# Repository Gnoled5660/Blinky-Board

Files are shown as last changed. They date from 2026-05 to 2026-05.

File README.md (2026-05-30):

Bildschirmfoto 2026-05-30 um 00 24 46

# Blinky-Board

This is my first ever designed PCB! With no experience and knowledge, I decided to follow a guide that CAN and Tanishq made. Their guide is super well done and gave me everything I needed to understand what I was doing. This PCB is a Blinky Board with a timer, so that the LEDs keep blinking after another. I have never made a PCB before and I was always afraid to make my own, because it seemed so overwhelming. But now I have realised that it isn't that difficult after all. I got familiar with using KiCad and I look forward to design more custom PCBs of my own. 

The first step was to wire the logical symbols. The PCB is mainly split into two section. One section is the clock/timer that sends signals to the LED controller. The other section is the LED controller, that controls the LEDs directly. 

Bildschirmfoto 2026-05-30 um 00 23 44

The next step was to assign the footprints. After assigning them, I needed to actually wire them. Since this is a two layer PCB, it was either first layer or second layer. I tried to organize the wires but it felt impossible. In the end, I managed to wire everything. However, it looks super chaotic to me. I will try and do better next time! Some 3D models were not available in KiCad which is why, I had to download them from a website.

I added a bunch of memes on the board, so that it doesn't look empty. It looks really cool to me with all the prints on the board.

Bildschirmfoto 2026-05-29 um 20 34 48

Zine

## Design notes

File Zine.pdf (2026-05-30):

# My first Blinky Board

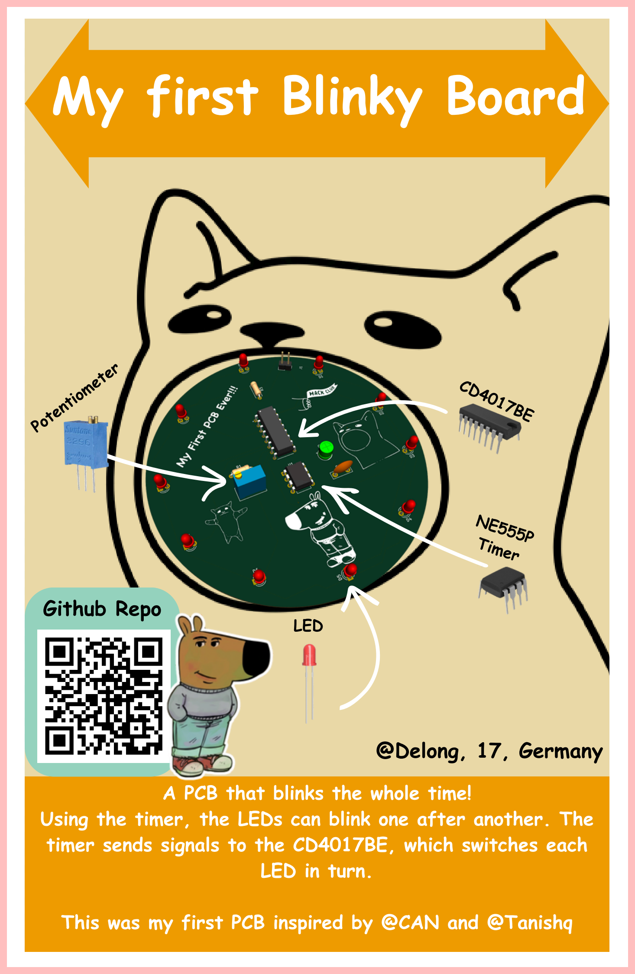
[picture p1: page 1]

Github Repo

@Delong, 17, Germany

CD4017BE

NE555P
Timer

LED

A PCB that blinks the whole time! Using the timer, the LEDs can blink one after another. The timer sends signals to the CD4017BE, which switches each LED in turn.

This was my first PCB inspired by @CAN and @Tanishq

Potentiometer

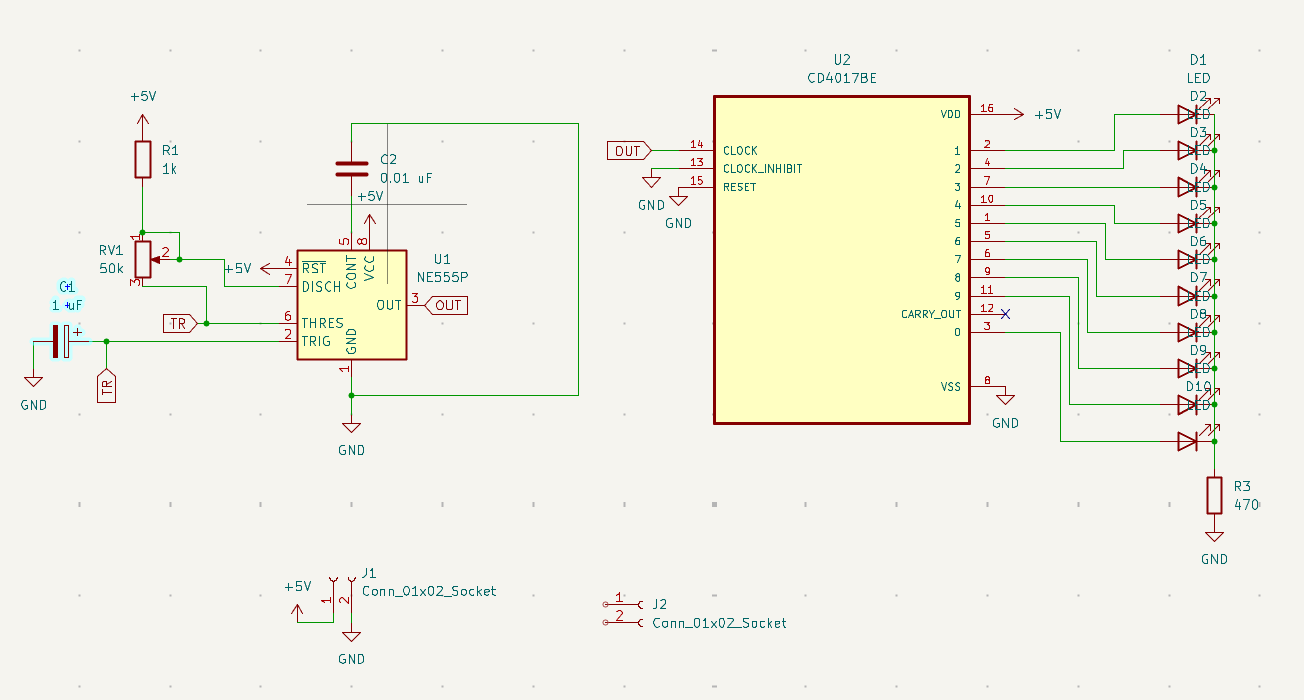
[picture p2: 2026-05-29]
Schematic/Schematic Symbol.png

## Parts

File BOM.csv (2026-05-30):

Name | Function | Links | Cost (USD) | Quantity
Capacitor | Polarized capacitor | https://funduinoshop.com/en/components/passive-components/capacitors/electrolytic-capacitor-1uf/10v-wired | 0.35 | 1
Capacitor | Unpolarized capacitor | https://www.ato.com/0-01μf-100v-ceramic-capacitor | 01.04 | 1
LED | LED Light | https://www.reichelt.de/de/de/shop/produkt/led_5_mm_bedrahtet_rot_125_mcd_50_-230920?PROVID=2788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 | 01.05 | 10
Resistor | Protect LED | https://www.reichelt.de/de/de/shop/produkt/widerstand_metalloxidschicht_470_ohm_0414_2_w_5_-2354 | 0.15 | 1
Resistor | Used as signal transmission | https://www.reichelt.de/de/de/shop/produkt/melf_widerstand_0204_1k_ohm_400_mw_1_-277763 | 0.08 | 1
Potentiometer | regulate LED speed | https://www.reichelt.de/de/de/shop/produkt/praezisionspotentiometer_25_gaenge_stehend_50_kohm-2710 | 2.10 | 1
NE555P | Timer LED light ticks | https://www.reichelt.de/de/de/shop/produkt/timer-ic_typ_555_dip-8-13397 | 0.3 | 1
CD4017BE | Control the LED | https://www.reichelt.de/de/de/shop/produkt/flip-flop_d-type_cmos_3_15_v_dip-16-12564 | 01.05 | 1
PCB | Main Circuit Board | https://jlcpcb.com | 9 | 1

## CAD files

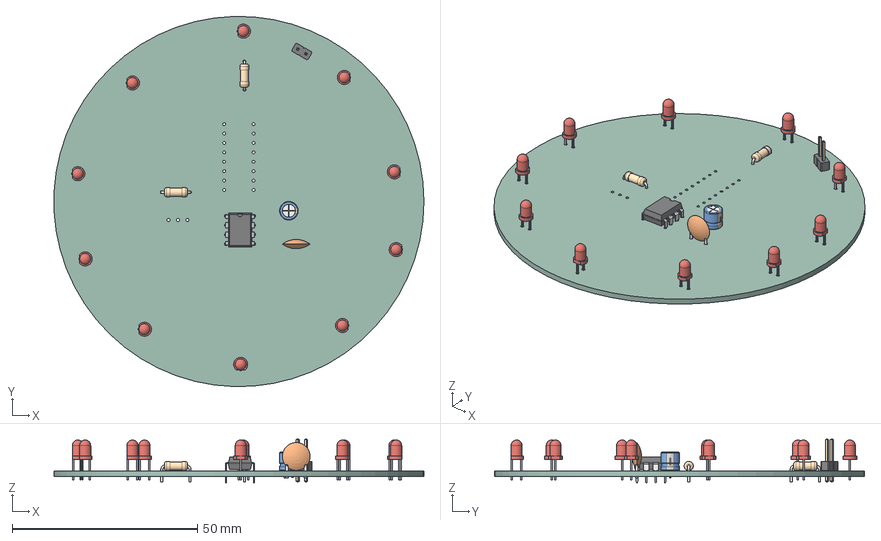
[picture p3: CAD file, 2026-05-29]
Schematic/3D Model.step
99.9 x 100.0 x 11.8 mm
LED_D3.0mm x 10
R_Axial_DIN0207_L63mm_D25mm_P762mm_Horizontal x 2
PinHeader_1x02_P254mm_Vertical
DIP-8_W7.62mm
CP_Radial_D50mm_P200mm
C_Disc_D75mm_W25mm_P500mm
Blinky Board_PCB

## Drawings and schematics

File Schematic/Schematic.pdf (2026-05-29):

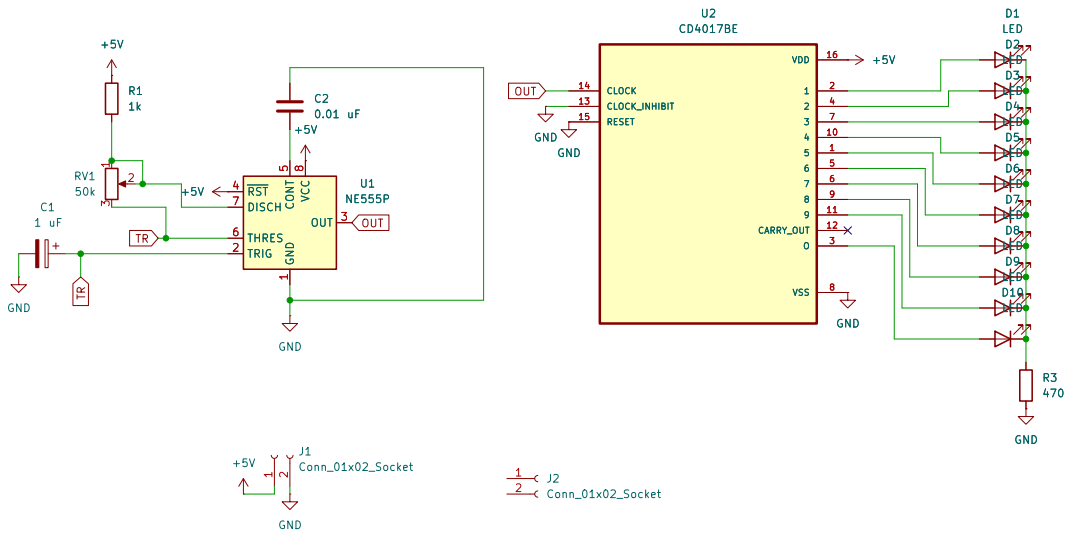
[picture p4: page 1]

Size: A4 | Rev:
KiCad E.D.A. 10.0.3 | Id: 1/1

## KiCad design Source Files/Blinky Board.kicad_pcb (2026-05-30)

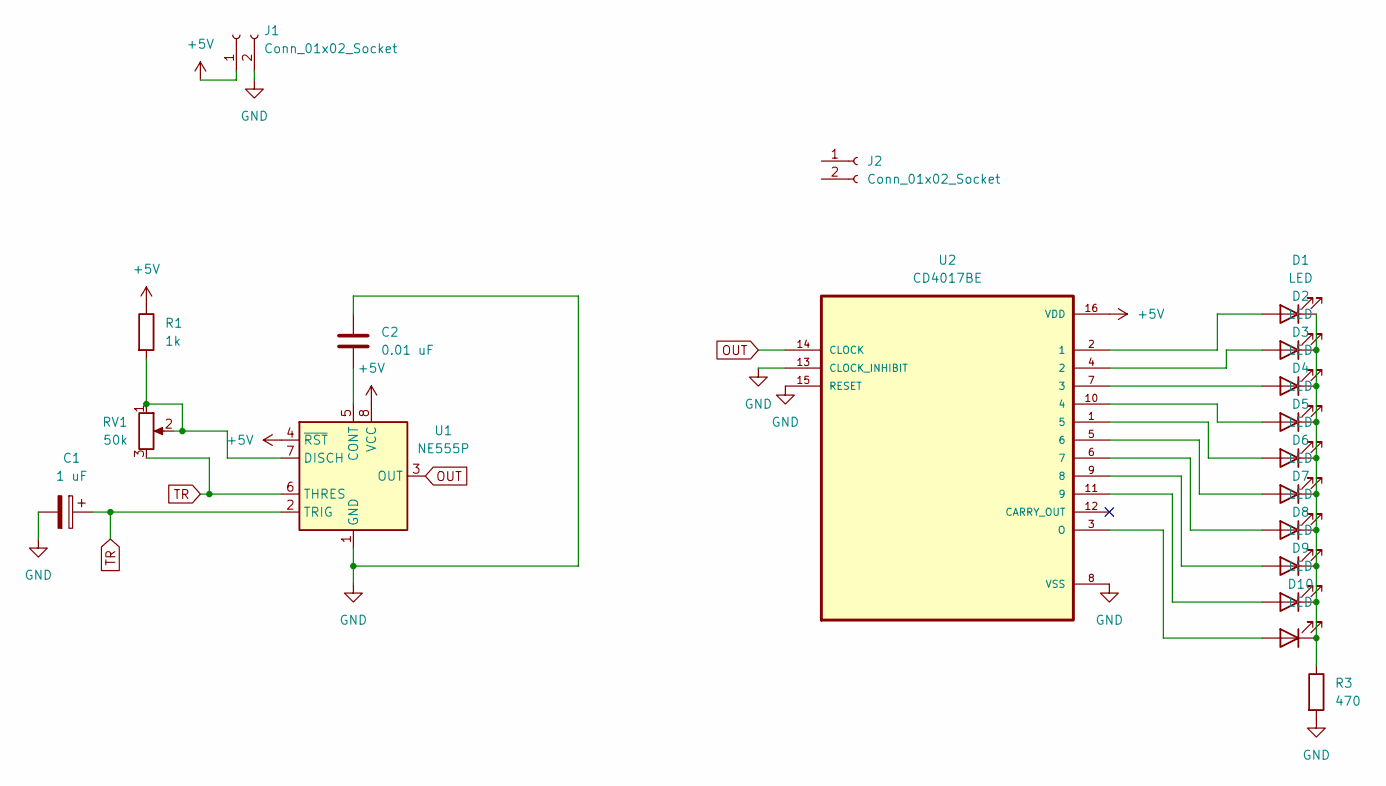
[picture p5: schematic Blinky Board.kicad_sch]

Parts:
C1: 1 uF; CP_Radial_D5.0mm_P2.00mm
C2: 0.01 uF; C_Disc_D7.5mm_W2.5mm_P5.00mm
D1, D2, D3, D4, D5, D6, D7, D8, D9, D10: LED; LED_D3.0mm
J1, J2: Conn_01x02_Socket; PinHeader_1x02_P2.54mm_Vertical
R1: 1k; R_Axial_DIN0207_L6.3mm_D2.5mm_P7.62mm_Horizontal
R3: 470; R_Axial_DIN0207_L6.3mm_D2.5mm_P7.62mm_Horizontal
RV1: 50k; Potentiometer_Vishay_T93YA_Vertical
U1: NE555P; DIP-8_W7.62mm
U2: CD4017BE; DIP794W45P254L1969H508Q16

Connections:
+5V: J1.1, R1.1, U1.4 (~RST), U1.8 (VCC), U2.16 (VDD)
GND: C1.2, C2.1, J1.2, R3.2, U1.1 (GND), U2.8 (VSS), U2.13 (CLOCK_INHIBIT), U2.15 (RESET)
unnamed: D1.2 (A), U2.2 (1)
unnamed: D1.1 (K), D2.1 (K), D3.1 (K), D4.1 (K), D5.1 (K), D6.1 (K), D7.1 (K), D8.1 (K), D9.1 (K), D10.1 (K), R3.1
unnamed: D2.2 (A), U2.4 (2)
unnamed: D3.2 (A), U2.7 (3)
unnamed: D4.2 (A), U2.10 (4)
unnamed: D5.2 (A), U2.1 (5)
unnamed: D6.2 (A), U2.5 (6)
unnamed: D7.2 (A), U2.6 (7)
unnamed: D8.2 (A), U2.9 (8)
unnamed: D9.2 (A), U2.11 (9)
unnamed: D10.2 (A), U2.3 (O)
unnamed: C2.2, U1.5 (CONT)
unnamed: R1.2, RV1.1, RV1.2, U1.7 (DISCH)
OUT: U1.3 (OUT), U2.14 (CLOCK)
TR: C1.1, RV1.3, U1.2 (TRIG), U1.6 (THRES)

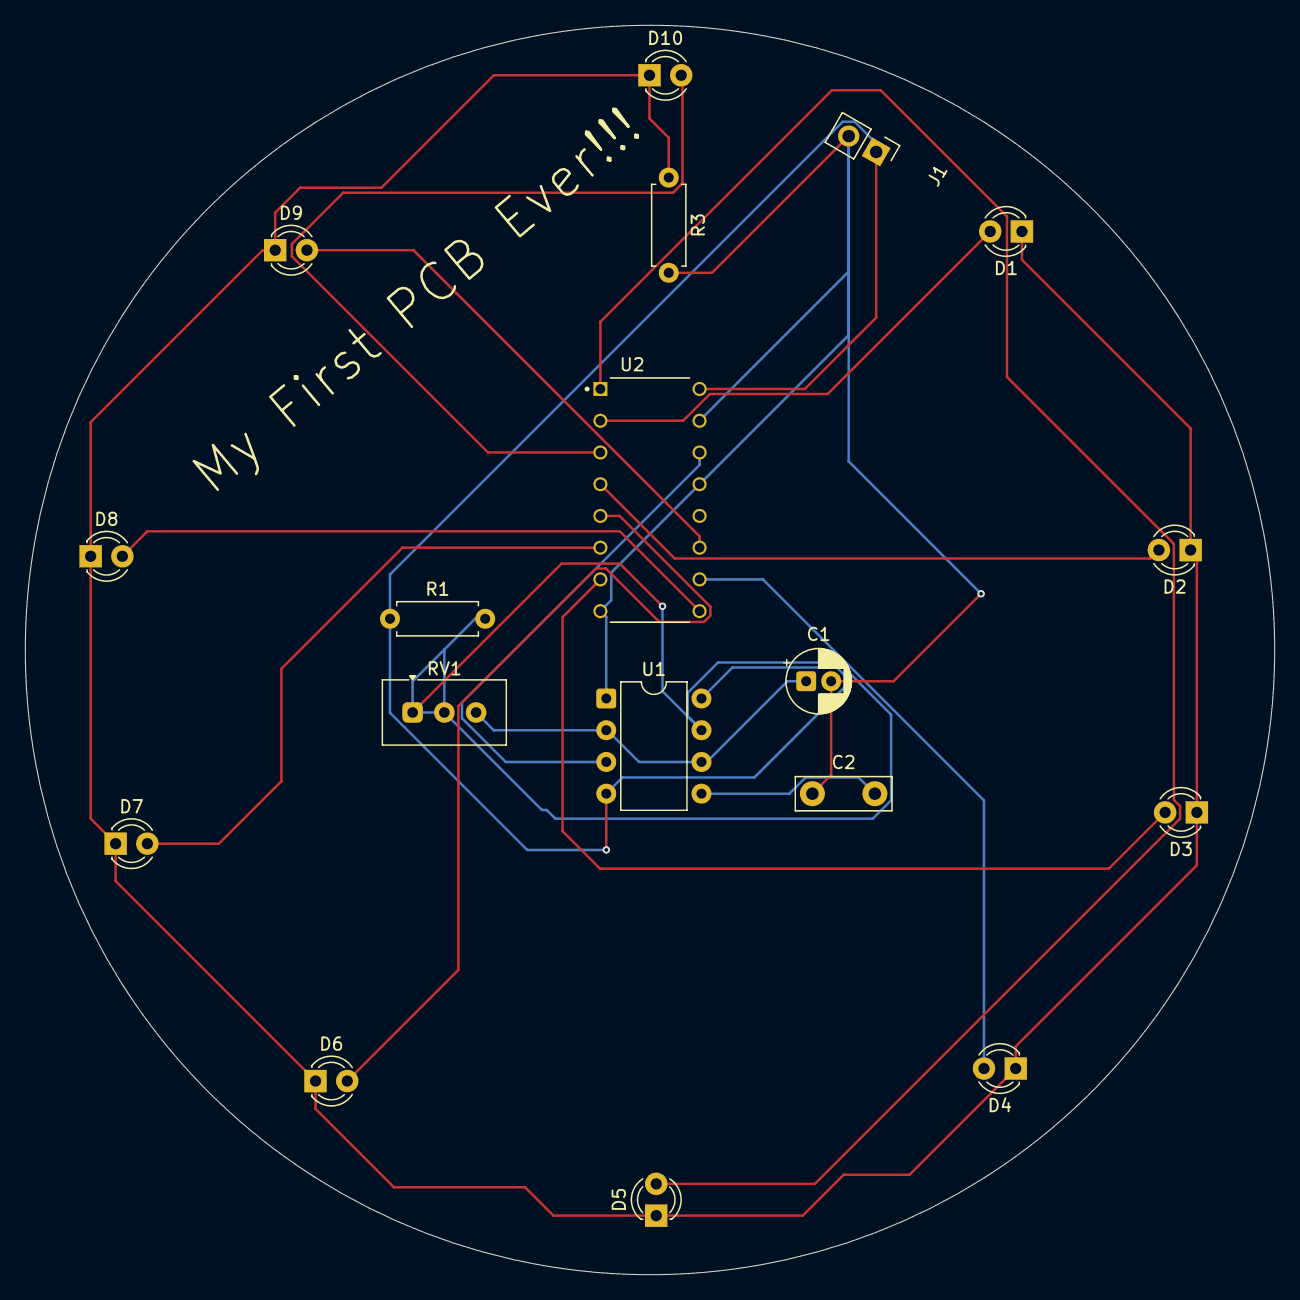
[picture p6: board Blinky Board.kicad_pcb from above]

Board: 2 copper layers, 100.0 x 100.0 mm, 18 parts (0 on the bottom side), 17 nets.

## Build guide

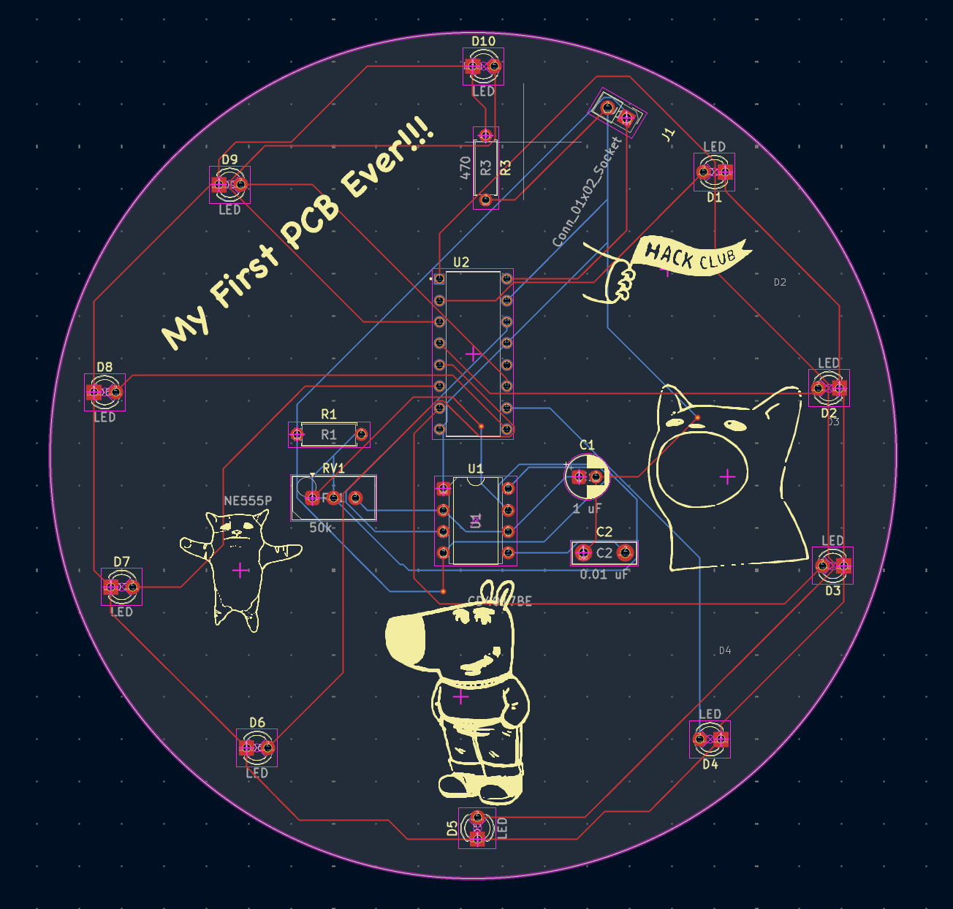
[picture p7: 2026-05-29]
Schematic/Footprint Wiring.png

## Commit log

2026-05-29 Rename Bildschirmfoto 2026-05-29 um 20.34.48.png to Footprint Wiring.png
2026-05-29 Rename Bildschirmfoto 2026-05-29 um 20.56.26.png to Schematic Symbol.png
2026-05-30 Update links in BOM.csv for PCB and components
    [BOM.csv]
2026-05-30 Rename Unbenannte Tabelle - BOM-3.csv to BOM-3.csv
    [BOM-3.csv]
